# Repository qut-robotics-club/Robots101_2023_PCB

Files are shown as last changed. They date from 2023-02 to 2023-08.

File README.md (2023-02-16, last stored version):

# ROBOTS101_2023

Goal:
To create a easy funtional Pi hat for the ROBOTS101 program.

This pi hat will:
- Label all pins & connections clearly.
- Have breakout headers to reduce confusion and reduce dangerous connections
- Regulate battery voltage & power the Pi safely 
- Provide a direct and clear power switch
- (Optional) Expand GPIO for future projects 
- Clean and streamline robot construction.
- Have an easy design for future PCB workshop to work on

ROBOTS101 WIKI LINK: https://goofy-slicer-49c.notion.site/ROBOTS101-Wiki-223888f84ce34d78a62f8b15874e6fb9

## Key Features
1. Battery Connector
    - XT30 PCB Mount
2. Power Regulation 
    - 5.1V Regulation
        - Limit to 2.5A
        - Needs filtering capacitors
        - Regulators can be bought from store
    - 3.3V Regulation? (unsure if necessary)
3. Reverse Polarity 
    - P-MOSFET
4. User Feedback
    - Buttons
    - LEDS
5. Expansion 
    - I2C address lanes - breakout into multiple connectors
6. Breakouts
    - Motor control board
    - Single Gripper Servo or two??
    - Ultrasonic Sensor
    - Adafruit Mini PiTFT support

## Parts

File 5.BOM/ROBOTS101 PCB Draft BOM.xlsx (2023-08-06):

ROBOTS101 PCB V2 BOM | Order Qty |  | 30
ITEM | TYPE | have / NOT needed? | QTY | INDIVIDUAL COST | PO Qty | order cost | LINK |  |  |  |  |  |  |  | 127 | https://www.altronics.com.au/p/z6334-dc-dc-buck-module-3-40v-input/
BACK POWER MODULE |  |  |  | for 1 |  | for 30
DMG2305UX-7 | BACKPOWER PNP MOSFET |  | 1 | 0.428 |  | 12.84 | https://au.mouser.com/ProductDetail/Diodes-Incorporated/DMG2305UX-7?qs=L1DZKBg7t5F%2FNBHrjfxC%252Bg%3D%3D |  |  | $0.49 | https://www.digikey.com.au/en/products/detail/diodes-incorporated/DMG2305UX-7/4340667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
DMMT5401-7-F | BACKPOWER PAIRED TRANSISTORS | x | 1 | 0.662 |  | 19.86 | https://au.mouser.com/ProductDetail/Diodes-Incorporated/DMMT5401-7-F?qs=hiZRsJxw0h3f7LzTPwvEFQ%3D%3D
Total cost for order |  |  |  | $0.43 |  | $12.84
BUCK REG |  |  |  | for 1 |  | for 30
SRR1260-330M | FIXED IND 33UH 3A 60 MOHM SMD |  | 1 | $1.67 |  | $50.10 | https://www.digikey.com.au/en/products/detail/bourns-inc/SRR1260-330M/1969960 | $0.93 | https://www.digikey.com.au/en/products/detail/tai-tech-advanced-electronics-co-ltd/TMPC-1004H-470MG-D/17835596
LM2596DSADJG | DC-DC Switching Buck (Step Down) Regulator, Adj., 4.5V-40Vin, 1.23V-37V/3A out, 150 kHz, TO-263-5 |  | 1 | $3.79 |  | $113.70 | https://au.element14.com/on-semiconductor/lm2596dsadjg/dc-dc-conv-buck-3a-150khz-to-263/dp/2534162?st=lm2596 |  |  |  |  | ALTERNATIVLY | $0.94 | https://au.mouser.com/ProductDetail/Texas-Instruments/TPS62933PDRLR?qs=vvQtp7zwQdPCuPvhGs%2FYxA%3D%3D
SK34A | DIODE SCHOTTKY 40V 3A SMA |  | 1 | $0.55 |  | $16.50 | https://www.digikey.com.au/en/products/detail/smc-diode-solutions/SK34A/6022681
 | caps |  | 1 | $0.57
Total cost for order |  |  |  | $6.58 |  | $197.52
NEOPIXEL CIRCUIT |  |  |  | for 1 |  | for 30
1655 | ADDRESS LED DISC SERIAL RGB 1=10 | x | 1 | $0.70 |  | $20.91 | https://www.digikey.com.au/en/products/detail/1655/1528-1104-ND/5154679?curr=usd
750-SS8050-G | Bipolar Transistors - BJT NPN TRANSISTOR 1.5A 40V | x | 1 | $0.36 |  | $10.71 | https://au.mouser.com/ProductDetail/Comchip-Technology/SS8050-G?qs=LLUE9lz1YbcHg%252BWLMAtcrQ%3D%3D
WS2812B v5 | GlowBit LED 20 Pack - Black (WS2812B v5) NeoPixel Compatible |  | 1 | $0.52 |  | $10.30 | https://core-electronics.com.au/glowbit-led-20-pack-black-ws2812b-v5-neopixel-compatible.html
Total cost for order |  |  |  | $0.52 |  | $15.45
BATTERY INDICATOR |  |  |  | for 1 |  | for 30
750-SS8050-G | Bipolar Transistors - BJT NPN TRANSISTOR 1.5A 40V |  | 1 | $0.36 |  | $10.71 | https://au.mouser.com/ProductDetail/Comchip-Technology/SS8050-G?qs=LLUE9lz1YbcHg%252BWLMAtcrQ%3D%3D
AZ431AN-ATRE1 | Voltage References Adj Prec Shunt Reg 2.5V to 36V 4.5mV |  | 1 | $0.47 |  | $14.01 | https://au.mouser.com/ProductDetail/Diodes-Incorporated/AZ431AN-ATRE1?qs=eSfX1CQlHqrfix60%252BW9M8g%3D%3D
CRGCQ0805F180K | RES 180K OHM 1% 1/8W 0805 |  | 1 | 0.0298 | 100 | 2.98 | https://www.digikey.com.au/en/products/detail/CRGCQ0805F180K/A129776CT-ND/8577608?curr=usd
Total cost for order |  |  |  | $0.82 |  | $24.72
ULTRASONIC
 | 470 Ohm |  |  |  | 100
 | 330 Ohm
CRG0805F2K0 | RES SMD 2K OHM 1% 1/8W 0805 |  | 2 | $0.03 | 200 | $5.72 | https://www.digikey.com.au/en/products/detail/CRG0805F2K0/A126358CT-ND/7603413?curr=usd
 |  |  |  | for 1 |  | for 30
ALL TOGETHER circuit components |  |  |  | $8.35 |  | $250.53
PCB Fabrication |  |  |  |  |  | $60.43
ADD ON TO BOCHRA ORDER |  |  |  | Individual Cost | PO Qty | PO cost
240PCS/M2.5(Black) | HVAZI 240pcs M2.5 Nylon Hex Spacer Standoffs Screws Nuts Assortment Kit;Male-Female(Black) |  |  | 33.47 | 4 | 133.88 | https://www.amazon.com.au/HVAZI-240pcs-Standoffs-Assortment-Male-Female/dp/B07JYSFMRY
P5387 | 2 x 20 Pin 11mm Stackable Header Socket |  |  | 3.6 | 10 | 36 | https://www.altronics.com.au/p/p5387-oupiin-2-x-20-pin-11mm-stackable-header-socket/
TPEXRE650 | TP-LINK AC2600 WiFi Range Extender RE650 |  |  | 167 | 1 | 167 | https://www.officeworks.com.au/shop/officeworks/p/tp-link-ac2600-wifi-range-extender-re650-tpexre650
All Together PO |  |  |  |  |  | $647.84

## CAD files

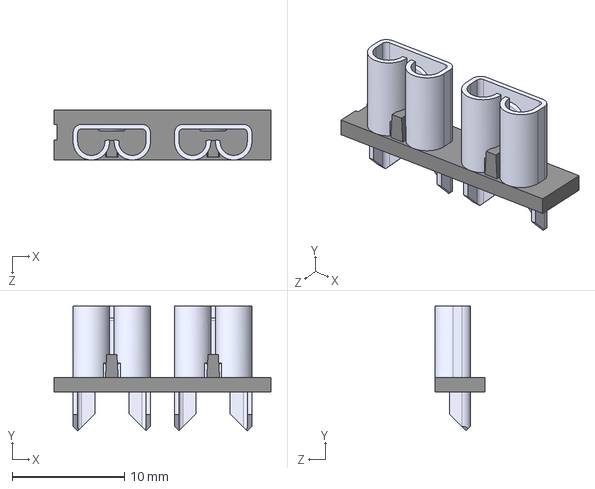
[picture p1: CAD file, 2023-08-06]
4.CAD/XT30PW-M/3522-2--3DModel-STEP-56544.STEP
19.3 x 11.1 x 4.45 mm

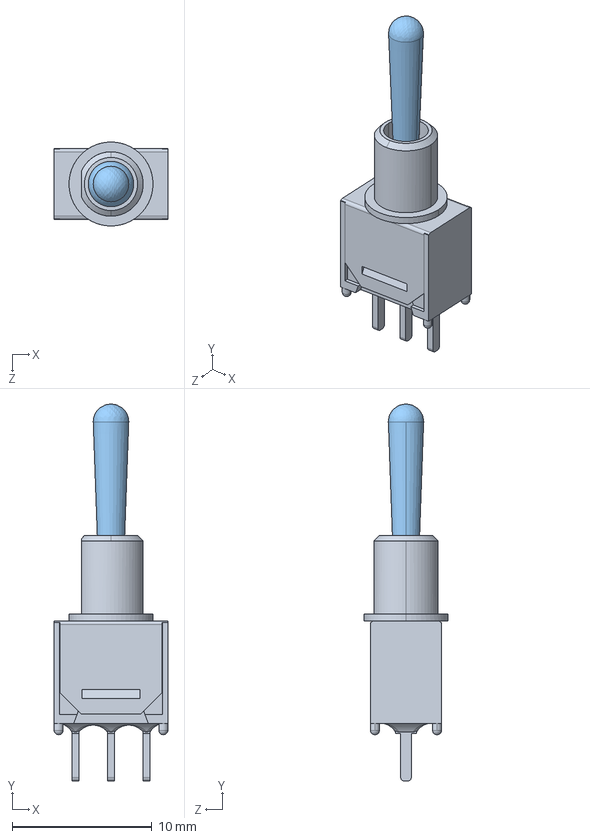
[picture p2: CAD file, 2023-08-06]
4.CAD/XT30PW-M/200MSP3T1B1M2QEH--3DModel-STEP-613395.STEP
8.13 x 26.9 x 6.00 mm

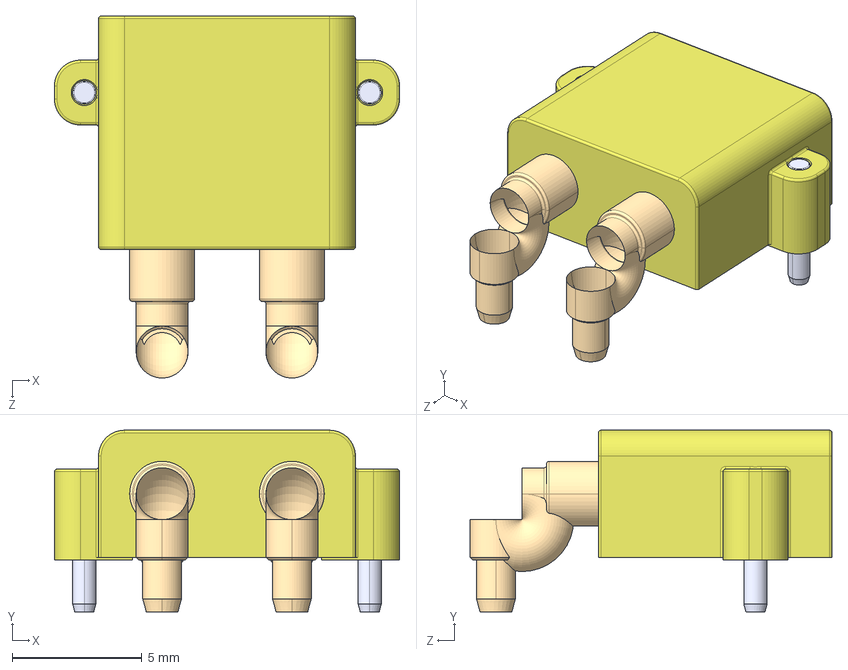
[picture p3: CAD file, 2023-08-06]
4.CAD/XT30PW-M/XT30PW-M--3DModel-STEP-1.STEP
13.3 x 7.00 x 14.0 mm

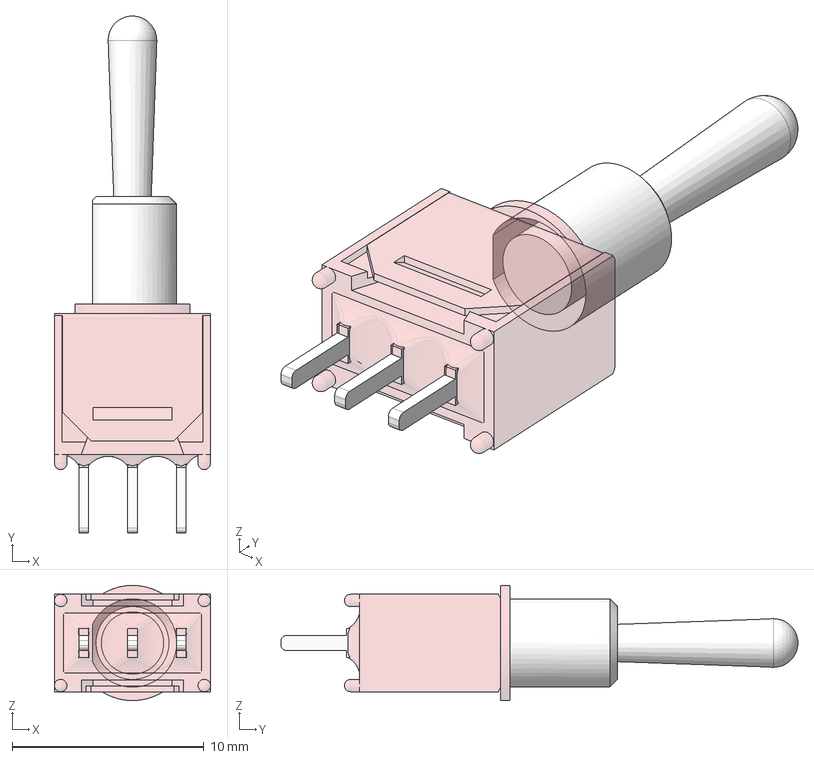
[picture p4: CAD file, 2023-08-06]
4.CAD/XT30PW-M/200MSP3T1B1M2QEH-Switch-Colored.stp
8.13 x 26.9 x 6.00 mm

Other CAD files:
4.CAD/XT30PW-M/200MSP3T1B1M2QEH--3DModel-STEP-613395_Simplify_2.ipt

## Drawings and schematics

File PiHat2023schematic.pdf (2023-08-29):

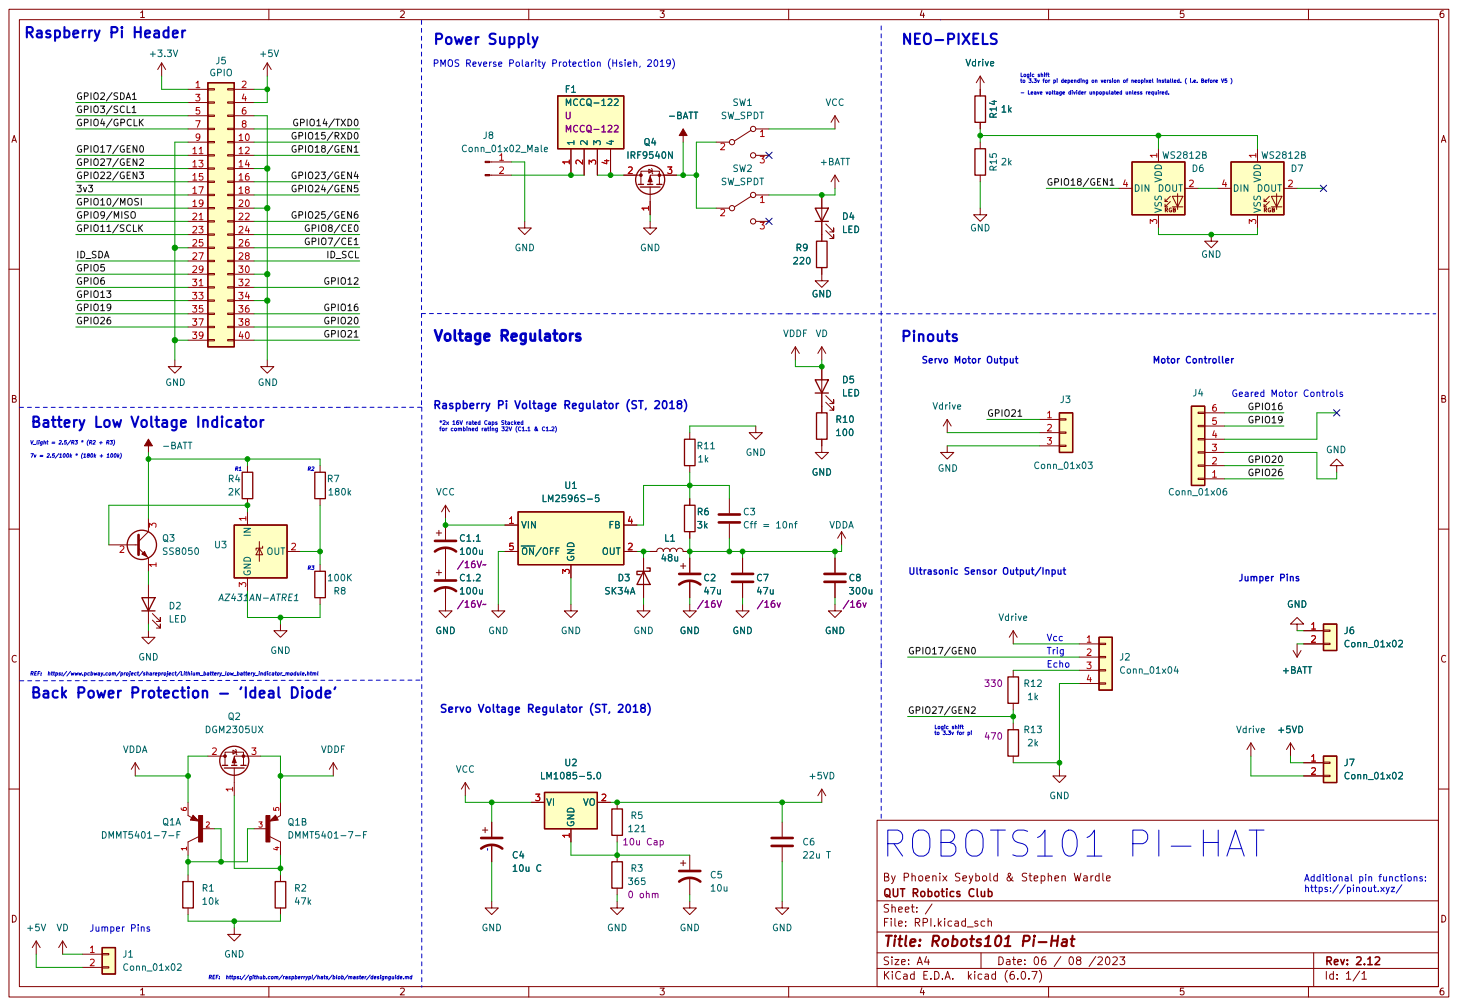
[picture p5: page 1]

for combined rating 32V (C1.1 & C1.2) Raspberry Pi Header

PMOS Reverse Polarity Protection (Hsieh, 2019)

Logic shift
to 3.3v for pi depending on version of neopixel installed. ( i.e. Before V5 )

- Leave voltage divider unpopulated unless required. Voltage Regulators
3 SW1 SW_SPDT C1.2

https://pinout.xyz/ Motor Controller Geared Motor Controls Echo Trig

Battery Low Voltage Indicator

3 FB 4 ~{ON}/OFF 5 GND

R3 REF: https://www.pcbway.com/project/shareproject/Lithium_battery_low_battery_indicator_module.html Back Power Protection - 'Ideal Diode'

Ultrasonic Sensor Output/Input

By Phoenix Seybold & Stephen Wardle
File: RPI.kicad_sch Sheet: / QUT Robotics Club

Id: 1/1 Title: Robots101 Pi-Hat

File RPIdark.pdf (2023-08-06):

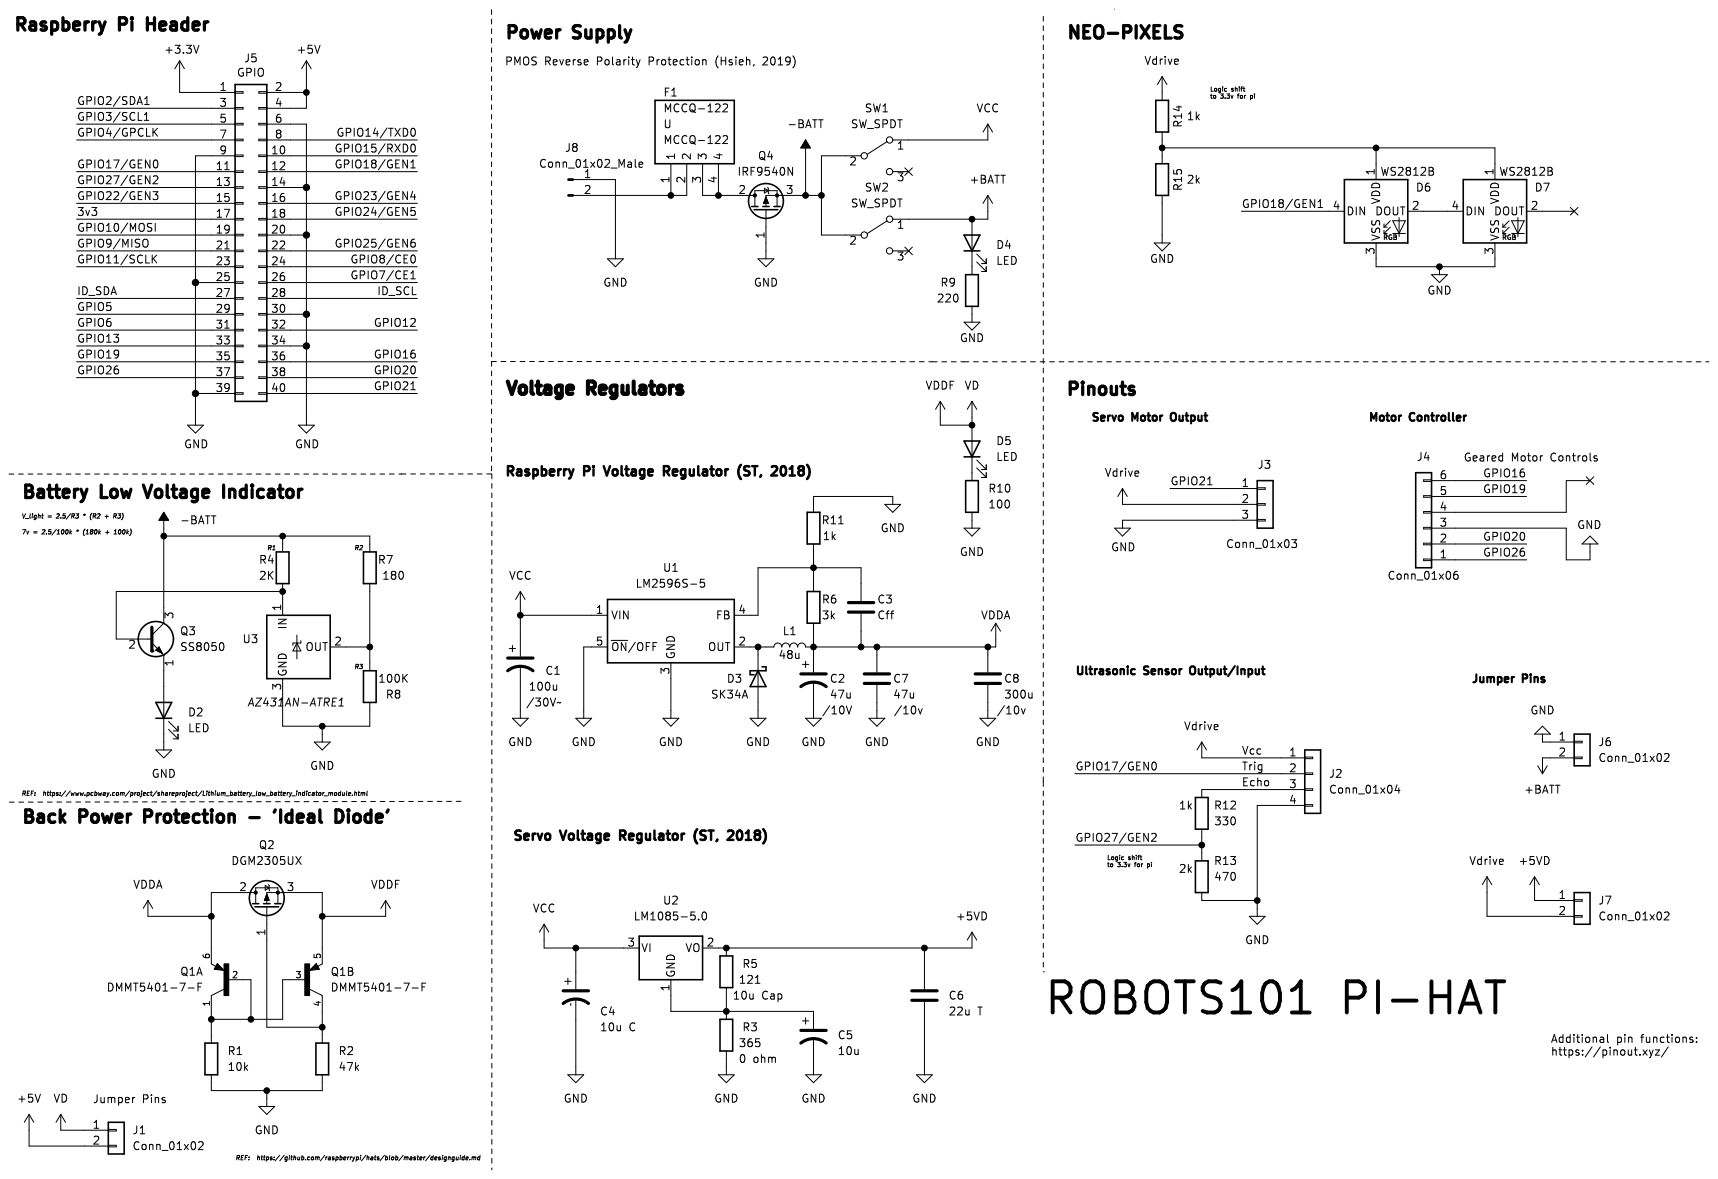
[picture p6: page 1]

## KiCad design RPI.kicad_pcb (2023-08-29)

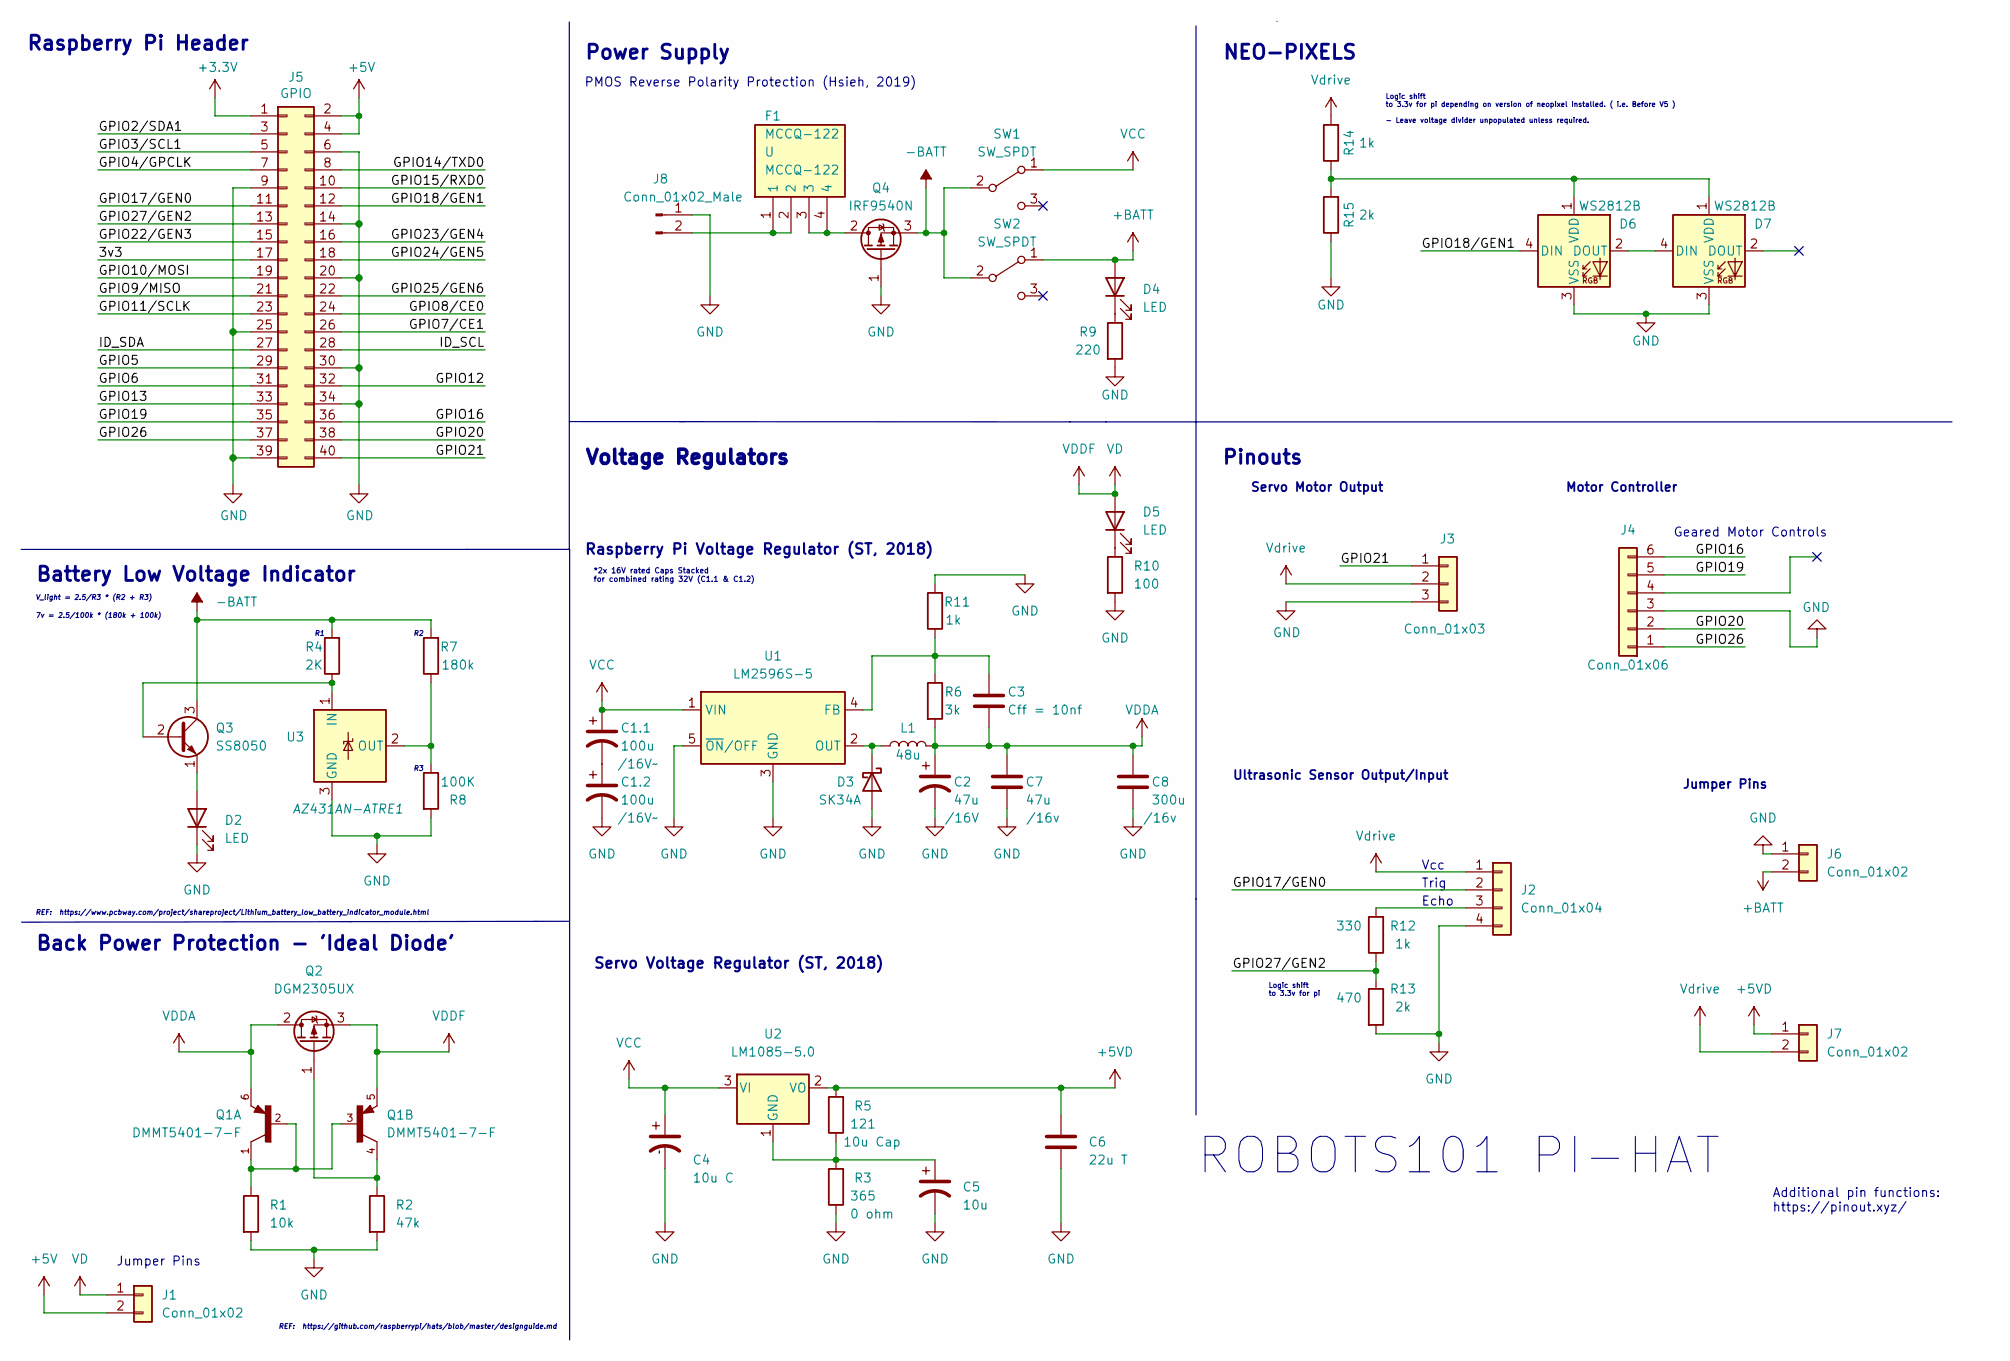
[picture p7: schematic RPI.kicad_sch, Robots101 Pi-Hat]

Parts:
C1.1, C1.2: 100u; C_1210_3225Metric_Pad1.33x2.70mm_HandSolder; Voltage /16V~
C2: 47u; C_0805_2012Metric_Pad1.18x1.45mm_HandSolder; Voltage /16V
C3: Cff = 10nf; C_0805_2012Metric_Pad1.18x1.45mm_HandSolder
C4: 10u C; C_0805_2012Metric_Pad1.18x1.45mm_HandSolder
C5: 10u; C_0805_2012Metric_Pad1.18x1.45mm_HandSolder
C6: 22u T; C_0805_2012Metric_Pad1.18x1.45mm_HandSolder
C7: 47u; C_0805_2012Metric_Pad1.18x1.45mm_HandSolder; Voltage /16v
C8: 300u; CP_Radial_D5.0mm_P2.50mm; Voltage /16v
D2, D4, D5: LED; D_0805_2012Metric_Pad1.15x1.40mm_HandSolder
D3: SK34A; D_SMA_Handsoldering
D6, D7: WS2812B; LED_WS2812B_PLCC4_5.0x5.0mm_P3.2mm
F1: MCCQ-122; MCCQ122; Manufacturer_Part_Number MCCQ-122
J1, J7: Conn_01x02; PinSocket_1x02_P2.54mm_Vertical
J2: Conn_01x04; PinSocket_1x04_P2.54mm_Vertical
J3: Conn_01x03; PinSocket_1x03_P2.54mm_Vertical
J4: Conn_01x06; PinSocket_1x06_P2.54mm_Vertical
J5: GPIO; PinSocket_2x20_P2.54mm_Vertical
J6: Conn_01x02; TE_282836-2
J8: Conn_01x02_Male; AMASS_XT30PW-M_1x02_P2.50mm_Horizontal
L1: 48u; L_Bourns_SRR1260
Q1: DMMT5401-7-F; SOT-23-6_Handsoldering; PARTREV 8
Q2: DGM2305UX; SOT-23
Q3: SS8050; SOT-23-3
Q4: IRF9540N; TO-220-3_Vertical
R1: 10k; R_0805_2012Metric_Pad1.20x1.40mm_HandSolder
R2: 47k; R_0805_2012Metric_Pad1.20x1.40mm_HandSolder
R3: 365; R_0805_2012Metric_Pad1.20x1.40mm_HandSolder
R4: 2K; R_0805_2012Metric_Pad1.20x1.40mm_HandSolder
R5: 121; R_0805_2012Metric_Pad1.20x1.40mm_HandSolder
R6: 3k; R_0805_2012Metric_Pad1.20x1.40mm_HandSolder
R7: 180k; R_0805_2012Metric_Pad1.20x1.40mm_HandSolder
R8: 100K; R_0805_2012Metric_Pad1.20x1.40mm_HandSolder
R9: 220; R_0805_2012Metric_Pad1.20x1.40mm_HandSolder
R10: 100; R_0805_2012Metric_Pad1.20x1.40mm_HandSolder
R11, R12, R14: 1k; R_0805_2012Metric_Pad1.20x1.40mm_HandSolder
R13, R15: 2k; R_0805_2012Metric_Pad1.20x1.40mm_HandSolder
SW1, SW2: SW_SPDT; Switch_SPDT_Jaycar
U1: LM2596S-5; TO-263-5_TabPin3
U2: LM1085-5.0; TO-220-3_Vertical
U3: AZ431AN-ATRE1; SOT-23-3

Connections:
+3V3: J5.1
+5V: J1.2, J5.2, J5.4
+5VD: C6.1, J7.1, R5.2, U2.2 (VO)
+BATT: D4.2 (A), J6.2, SW2.1 (A)
-BATT: Q3.3 (C), Q4.3 (S), R4.2, R7.2, SW1.2 (B), SW2.2 (B)
/3v3: J5.17
/GPIO2/SDA1: J5.3
/GPIO3/SCL1: J5.5
/GPIO4/GPCLK: J5.7
/GPIO5: J5.29
/GPIO6: J5.31
/GPIO7/CE1: J5.26
/GPIO8/CE0: J5.24
/GPIO9/MISO: J5.21
/GPIO10/MOSI: J5.19
/GPIO11/SCLK: J5.23
/GPIO12: J5.32
/GPIO13: J5.33
/GPIO14/TXD0: J5.8
/GPIO15/RXD0: J5.10
/GPIO16: J4.6, J5.36
/GPIO17/GEN0: J2.2, J5.11
/GPIO18/GEN1: D6.4 (DIN), J5.12
/GPIO19: J4.5, J5.35
/GPIO20: J4.2, J5.38
/GPIO21: J3.1, J5.40
/GPIO22/GEN3: J5.15
/GPIO23/GEN4: J5.16
/GPIO24/GEN5: J5.18
/GPIO25/GEN6: J5.22
/GPIO26: J4.1, J5.37
/GPIO27/GEN2: J5.13, R12.1, R13.1
/ID_SCL: J5.28
/ID_SDA: J5.27
GND: C1.2.2, C2.2, C4.2, C5.2, C6.2, C7.2, C8.2, D2.1 (K), D3.2 (A), D6.3 (VSS), D7.3 (VSS), J2.4, J3.3, J4.3, J5.6, J5.9, J5.14, J5.20, J5.25, J5.30, J5.34, J5.39, J6.1, J8.1, Q4.1 (G), R1.2, R2.2, R3.1, R8.2, R9.2, R10.2, R11.2, R13.2, R15.1, U1.3 (GND), U1.5 (~ON/OFF), U3.3 (GND)
unnamed: C1.1.2, C1.2.1
unnamed: C3.1, R6.1, R11.1, U1.4 (FB)
unnamed: C5.1, R3.2, R5.1, U2.1 (GND)
unnamed: D2.2 (A), Q3.1 (E)
unnamed: D3.1 (K), L1.1, U1.2 (OUT)
unnamed: D4.1 (K), R9.1
unnamed: D5.1 (K), R10.1
unnamed: D6.1 (VDD), D7.1 (VDD), R14.1, R15.2
unnamed: D6.2 (DOUT), D7.4 (DIN)
unnamed: F1.1, F1.2, J8.2
unnamed: F1.3, F1.4, Q4.2 (D)
unnamed: J2.3, R12.2
unnamed: Q1.1, Q1.2, Q1.3, R1.1
unnamed: Q1.4, Q2.1 (G), R2.1
unnamed: Q3.2 (B), R4.1, U3.1 (IN)
unnamed: R7.1, R8.1, U3.2 (OUT)
VCC: C1.1.1, C4.1, SW1.1 (A), U1.1 (VIN), U2.3 (VI)
VD: D5.2 (A), J1.1, Q1.5, Q2.3 (S)
VDDA: C2.1, C3.2, C7.1, C8.1, L1.2, Q1.6, Q2.2 (D), R6.2
Vdrive: J2.1, J3.2, J7.2, R14.2

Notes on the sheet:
REF: https://github.com/raspberrypi/hats/blob/master/designguide.md
ROBOTS101 PI-HAT
Logic shift to 3.3v for pi
Battery Low Voltage Indicator
Raspberry Pi Header
Vcc
Jumper Pins
Pinouts
Additional pin functions: https://pinout.xyz/
Servo Motor Output
REF: https://www.pcbway.com/project/shareproject/Lithium_battery_low_battery_indicator_module.html
PMOS Reverse Polarity Protection (Hsieh, 2019)
V_light = 2.5/R3 * (R2 + R3)
*2x 16V rated Caps Stacked for combined rating 32V (C1.1 & C1.2)
Servo Voltage Regulator (ST, 2018)
Echo
Power Supply
Logic shift to 3.3v for pi depending on version of neopixel installed. ( i.e. Before V5 ) - Leave voltage divider unpopulated unless required.
Trig
Ultrasonic Sensor Output/Input
Back Power Protection - 'Ideal Diode'
Motor Controller
7v = 2.5/100k * (180k + 100k)
Raspberry Pi Voltage Regulator (ST, 2018)
Voltage Regulators
NEO-PIXELS
Geared Motor Controls

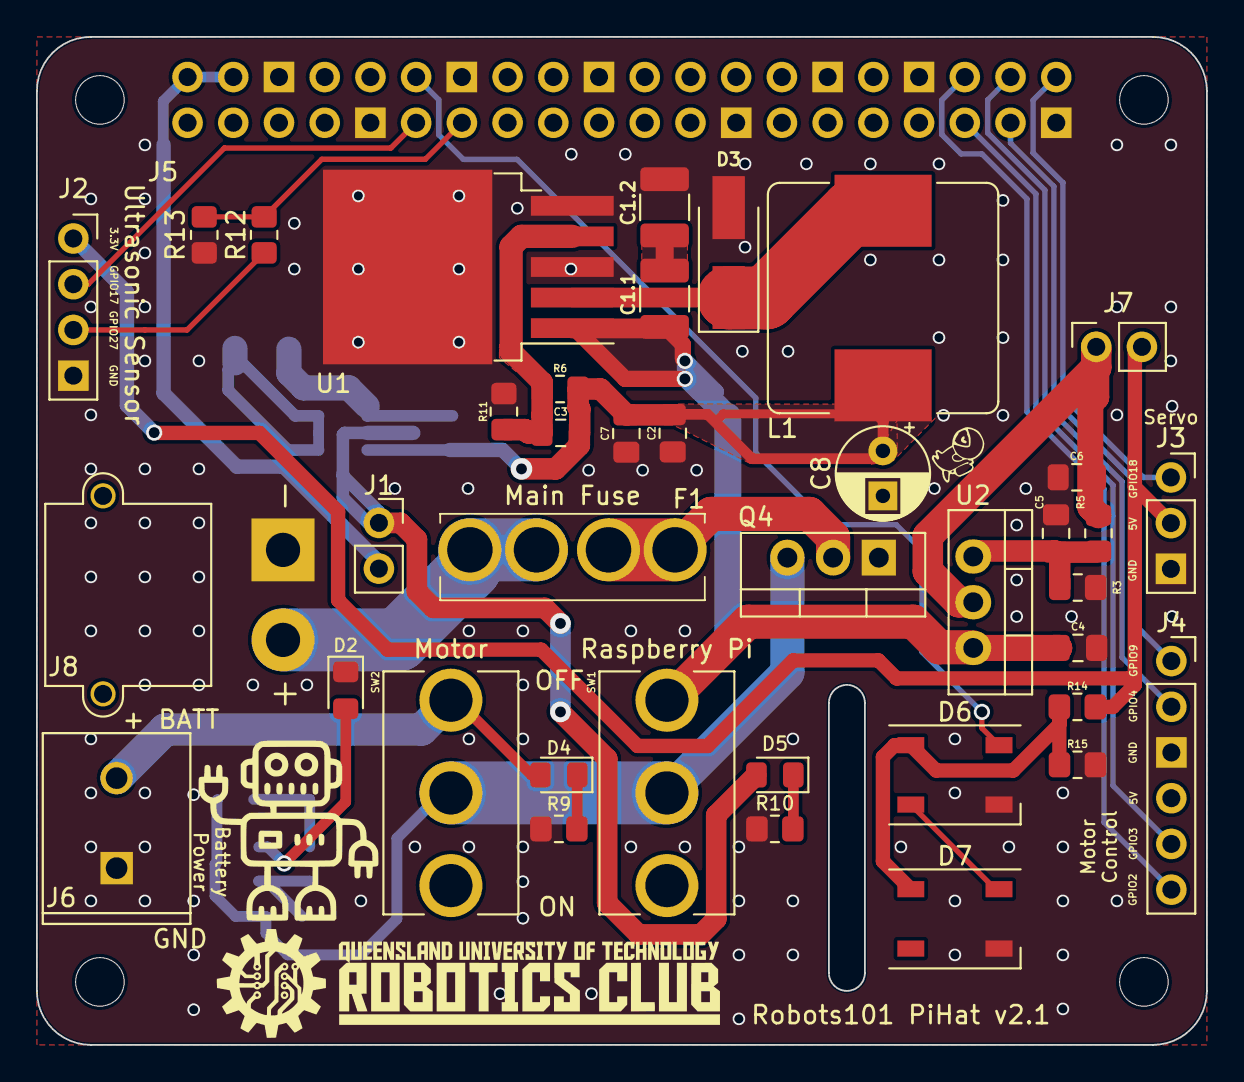
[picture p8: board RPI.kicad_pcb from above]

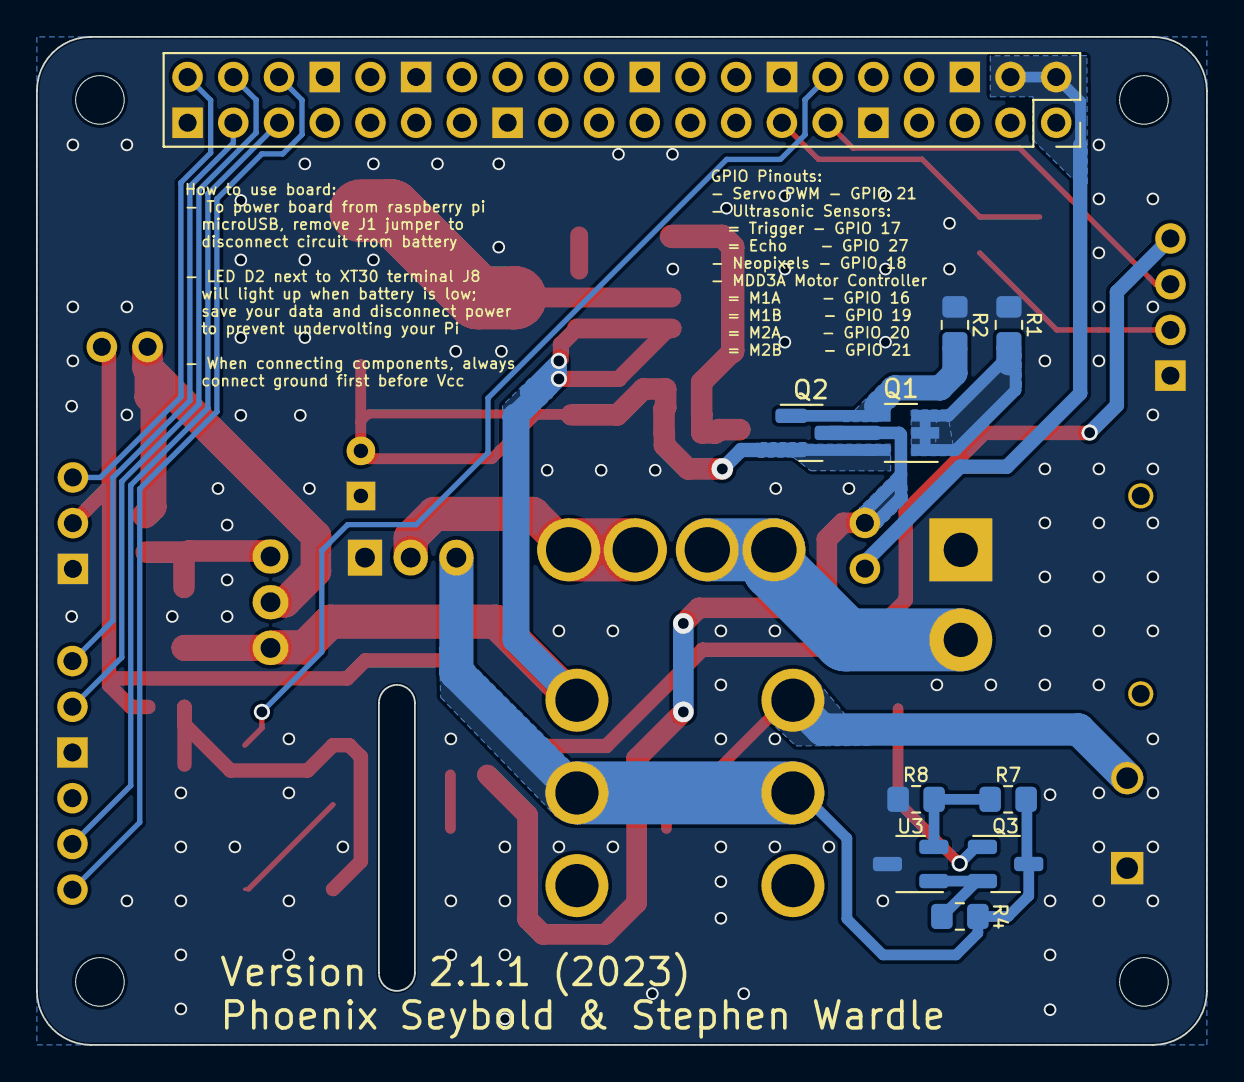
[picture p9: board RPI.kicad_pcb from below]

Board: 2 copper layers, 65.0 x 56.0 mm, 56 parts (10 on the bottom side), 33 nets.

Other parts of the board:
G: LOGO
G#2: LOGO
MH1, MH2, MH3, MH4: MountingHole_2.7mm_M2.5
ROBOTS101: LOGO

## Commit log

2023-02-13 adding stevens 1st PCB draft
    [RPI.kicad_pcb, RPI.kicad_sch]
2023-02-16 Updated MOSFET and Vreg to be store-accessible
    [RPI.kicad_sch]
2023-02-16 Updated Adafruit Pinouts & Pi Pinouts
    [RPI.kicad_sch]
2023-02-17 Adding part numbers + updated footprint for a pin
    [RPI.kicad_sch]
2023-03-01 Updated GPIO numbers correctly on pi
    [RPI.kicad_sch]
2023-03-02 Updates made to reflect actual correct pin labels
    [RPI.kicad_sch]
2023-03-02 Updated for motor driver, UV sensor, & servo pins
2023-03-02 Schematic Completed
    [RPI.kicad_sch]
2023-03-03 Added diode protection and switches
2023-03-03 Revisions made?
    [RPI.kicad_sch]
2023-03-03 Small update
    [RPI.kicad_sch]
2023-03-05 Removed EEPROM, Added back power protection
    [RPI.kicad_sch]
2023-03-15 Process to update headers for SMDs
    [RPI.kicad_sch]
2023-03-15 Component footprints done - only need cap & sw tbd
    [RPI.kicad_sch]
2023-03-19 Completed Schematic, just need to edit footprints
    [RPI.kicad_pcb, RPI.kicad_sch]
2023-03-27 All symbols updated
    [RPI.kicad_pcb]
2023-03-27 Checking about footprint
    [RPI.kicad_pcb]
2023-03-28 Official completion (Maybe add Gerald in)
    [RPI-B_Cu.gbl, RPI-B_Silkscreen.gbo, RPI-F_Cu.gtl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]
2023-03-28 Student Version
    [RPI.kicad_pcb, RPI.kicad_sch]
2023-03-28 Revert "Student Version"
    This reverts commit 96f77fa7ec59c85fd2b51f56cc1ae2b80deb0d98.
    [RPI.kicad_pcb, RPI.kicad_sch]
2023-03-31 Added Fuse
    [RPI.kicad_pcb, RPI.kicad_sch]
2023-03-31 Finalised for a check-up
    [RPI.kicad_pcb]
2023-03-31 Gerber files generated?
    [RPI-B_Cu.gbl, RPI-B_Silkscreen.gbo, RPI-F_Cu.gtl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]
2023-03-31 fixed up using Fab ruleset and Matt's input
    [RPI-B_Cu.gbl, RPI-B_Silkscreen.gbo, RPI-F_Cu.gtl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]
2023-03-31 Added load resistor & updated footprints
    [282836-2.step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]
2023-03-31 Further updated with more resistors
    [RPI-B_Cu.gbl, RPI-B_Silkscreen.gbo, RPI-F_Cu.gtl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]
2023-03-31 Updated parallel res due to poor understanding
    [RPI-B_Cu.gbl, RPI-B_Silkscreen.gbo, RPI-F_Cu.gtl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]
2023-04-01 Thickened 5V rail
    [RPI-B_Cu.gbl, RPI-B_Silkscreen.gbo, RPI-F_Cu.gtl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]
2023-04-01 Changed regulator
    [RPI-B_Cu.gbl, RPI-B_Silkscreen.gbo, RPI-F_Cu.gtl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]
2023-04-24 Added DMMT library
    [DMMT5401-7-F.step, RPI.kicad_sch]
2023-04-25 V2 Ready for checking
    [RPI-B_Cu.gbl, RPI-B_Silkscreen.gbo, RPI-F_Cu.gtl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]
2023-04-25 V2 update with THT copper shapes and info given
    [RPI-B_Cu.gbl, RPI-B_Silkscreen.gbo, RPI-F_Cu.gtl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]
2023-07-25 V2 Overhaul with new circuits and GPIO routes
    [282836-2.step, DMMT5401-7-F.step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]
2023-07-25 Complete file replacement to fix corrupted version
    [282836-2.step, DMMT5401-7-F.step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]
2023-08-01 Added via stitching and titles
    [RPI.kicad_pcb, RPI.kicad_sch, test.kicad_sch]
2023-08-01 Fixed trace thickness to 0.3 for R12 & R13
    [RPI.kicad_pcb]
2023-08-01 Thickened traces for Vcc
    [RPI.kicad_pcb]
2023-08-06 Updated Schematic & finalised PCB design
    - Schematic more readable
    - Finalised silkscreen
    - Generate Gerber
    - Cleaned Folder structure
    - Added missing 3D models
    [200MSP3T1B1M2QEH--3DModel-STEP-613395.STEP, 200MSP3T1B1M2QEH--3DModel-STEP-613395_Simplify_2.ipt, 200MSP3T1B1M2QEH-Switch-Colored.stp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]
2023-08-06 Slight placement adjustment of schematic
    [RPI.kicad_sch]
2023-08-06 added ref to Ideal diode
    [RPI.kicad_sch]
2023-08-06 Switch input cap to 1210 package for 100uf @16v
    [RPI.kicad_pcb, RPI.kicad_sch]
2023-08-06 minor Vias edits for text readability
    [RPI.kicad_pcb]
2023-08-06 minor readability tweaks
    [RPI.kicad_pcb]
2023-08-06 Updated drawing info
    [RPI.kicad_pcb, RPI.kicad_sch]
2023-08-06 fixed DRC Issues
    [RPI.kicad_pcb]
2023-08-06 minor fixes
    [RPI.kicad_sch]
2023-08-29 v2.1 Fixed Battery switch Direction
    Pushed after 2nd PCB order
    [RPI-B_Cu.gbl, RPI-B_Mask.gbs, RPI-B_Paste.gbp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]
